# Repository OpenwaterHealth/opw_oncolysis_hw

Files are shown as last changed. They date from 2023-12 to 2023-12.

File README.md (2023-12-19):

# Preclinical Oncolysis Prototype
This repository contains the hardware designs as well as assembly and operation instructions for Openwater's preclinical oncolysis platform. The Openwater Preclinical Oncolysis Prototype is designed to help researchers investigate the effect of different ultrasound parameters on a variety of in vitro and preclinical in vivo targets. Certain acoustic parameters may be well suited for damaging cancer cells while sparing surrounding healthy tissue, and this system is designed to systematically explore such effects in a laboratory setting. 

For additional details on the preclinical oncolysis system and its applications, refer to the [wiki](https://wiki.openwater.health/index.php/Openwater_Wiki#Oncolysis).

## Getting Started
In addition to gathering the hardware listed here and following assmebly instructions, the software control code for the system needs to be installed from this repository: [opw_oncolysis_sw](https://github.com/OpenwaterHealth/opw_oncolysis_sw)

## Files contained in the Openwater Oncolysis Hardware Repository
* [v1.2 Oncolysis User Manual](Oncolysis%20User%20Manual%20(V1.2).pdf)
  * This user manual is for the in vitro and in vivo systems. It includes:
    * List of components needed for each assembly with links to off-the-shelf components
    * Instructions for how to assemble all of the components for both setups
    * References to part numbers of 3D-printed parts 
* [in vitro setup components](in%20vitro%20setup)
* [in vivo setup components](in%20vivo%20setup)
* [acoustic output validation setup](acoustic%20output%20validation%20setup)

## Contributing
We welcome contributions from the community. If you have ideas for improvements or find any issues, please open an issue or submit a pull request.

Before contributing, please read our [Contributing Guidelines](CONTRIBUTING.md).

## License
This project is licensed under the AGPLv3 License - see the [License](LICENSE) file for details.

## Disclaimer
CAUTION - Investigational device. Limited by Federal (or United States) law to investigational use. This system has not been evaluated by the FDA and is not designed for the treatment or diagnosis of any disease. It is provided AS-IS, with no warranties. User assumes all liability and responsibility for identifying and mitigating risks associated with use

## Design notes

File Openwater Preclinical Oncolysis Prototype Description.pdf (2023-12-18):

# Preclinical Oncolysis Prototype

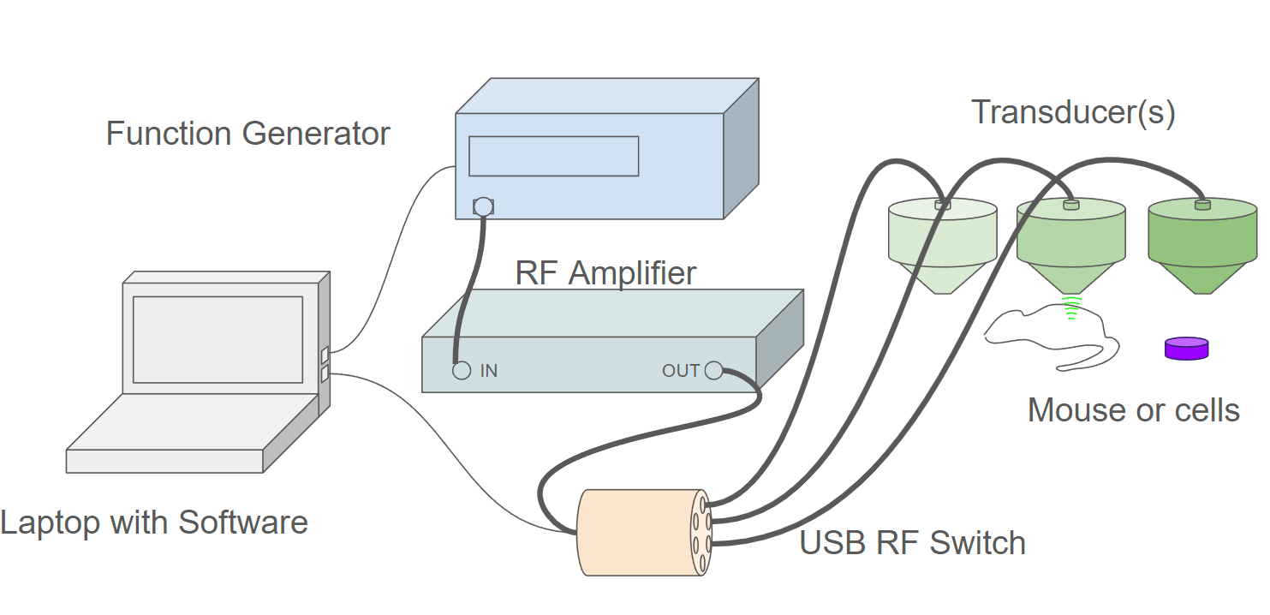
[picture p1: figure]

# Overview

The Openwater Preclinical Oncolysis Prototype is designed to help researchers investigate the effect of different ultrasound parameters on a variety of in vitro and preclinical in vivo targets. Certain acoustic parameters may be well suited for damaging cancer cells while sparing surrounding healthy tissue, and this system is designed to systematically explore such effects in a laboratory setting.

Multiple focused ultrasound transducers are connected to a programmable signal generator through an amplifier and a switch to select which transducer is active. Samples are placed beneath the transducer(s), using 3D-printed coupling cones filled with water to make a path for the ultrasound and set the depth of the focal spot within the target. This system is compatible with in vitro targets held in standard 6-well plates as well as with mouse flanks, through the
assistance of a stereotactic frame.

Controller software allows for configuration of
treatment parameters through a simple GUI application. With its default settings, the system can be configured to output focused ultrasound from the parameters shown in the table to the right. This allows for investigation of treatment parameters both within and well above the safety levels used for diagnostic ultrasound imaging.

# Getting Started

Additional information can be found in the following repositories:

- opw_oncolysis_hw (https://github.com/OpenwaterInternet/opw_oncolysis_hw) - assembly/operation instructions, mechanical drawings, 3D models
- opw_oncolysis_sw (https://github.com/OpenwaterInternet/opw_oncolysis_sw) - software to configure and operate the system
- opw_oncolysis_data (https://github.com/OpenwaterInternet/opw_oncolysis_data) - research data and experimental procedures

CAUTION - Investigational device. Limited by Federal (or United States) law to investigational use. This system has not been evaluated by the FDA and is not designed for the treatment or diagnosis of any disease. It is provided AS-IS, with no warranties. User assumes all liability and responsibility for identifying and mitigating risks associated with use

Parameter | Min | Max | Units
Frequency | 70 | 1000 | kHz
Output Voltage | 0 | 843 | V
Peak Negative Pressure | 0 | 1* | MPa
Mechanical Index | 0 | 3.8*
ISPPA | 0 | 100* | W/cm2
ISPTA | 0 | 1000* | mW/cm2
Burst Length | 2 | 40 | ms
Duty Cycle | 0.5 | 10 | %
Treatment Duration | 5 | 60 * 15 | seconds
*These are the maximum values that can be set when using the parameter as the target. If the parameter is derived and not used as the target, it may exceed this range to reach another parameter’s target value.

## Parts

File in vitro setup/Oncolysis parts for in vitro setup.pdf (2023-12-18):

# Oncolysis parts for v1.2 in vitro setup

- ONC- single treatment unit (assembly)
Off-the-shelf (OTS) parts (links)
- 1000-0173
- Acoustic absorbing foam (OTS) (https://www.acoustics.co.uk/product/apltile-sf5048/)
- 1000-0174
- Polysterene clear tank used in treatments (OTS) (https://www.usplastic.com/catalog/item.aspx?itemid=97006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)
- 1000-0175
- Internal O-ring for all the cones (OTS) (https://www.mcmaster.com/1288N237/)
- 1000-0176
- External O-ring for 25mm and 30mm cones (OTS) (https://www.mcmaster.com/5233T451/)
- 1000-0177
- External O-ring for 45mm and 60mm cones (OTS) (https://www.mcmaster.com/5233T442/)
- 1000-0178
- Thincert cell culture insert for 6 well plates (OTS) (https://shop.gbo.com/en/usa/products/bioscience/cell-culture-products/thincert-cell-culture-inserts/thincert-cell-culture-inserts-6well/657630.html) Tank covers zip
- 3000-0767
- Thincert holder/Laser cut in acrylic (3mm thickness)
- 3000-0768
- Hooks for Inner Tank Cover - 25mm, 3D printed
- 3000-0769
- Hooks for Inner Tank Cover - 30mm, 3D printed
- 3000-0770
- Hooks for Inner Tank Cover - 45mm, 3D printed
- 3000-0771
- Hooks for Inner Tank Cover - 60mm, 3D printed
Coupling cone zip
- 3000-0772
- 25mm cone used for 70,100 and 150kHz. 3D printed in 3rd party manufacturer (Xometry - Process: Stereolithography (SLA) Material: Accura ClearVue, Clear, Standard Resolution)
- 3000-0773
- 30mm cone used for 230 and 300kHz. 3D printed in 3rd party manufacturer (Xometry - Process: Stereolithography (SLA) Material: Accura ClearVue, Clear, Standard Resolution)
- 3000-0774
- 45mm cone used for 500 and 1000kHz. 3D printed in 3rd party manufacturer (Xometry - Process: Stereolithography (SLA) Material: Accura ClearVue, Clear, Standard Resolution)
- 3000-0775

- 60mm cone used for 670kHz. 3D printed in 3rd party manufacturer (Xometry -Process: Stereolithography (SLA) Material: Accura ClearVue, Clear, Standard Resolution)

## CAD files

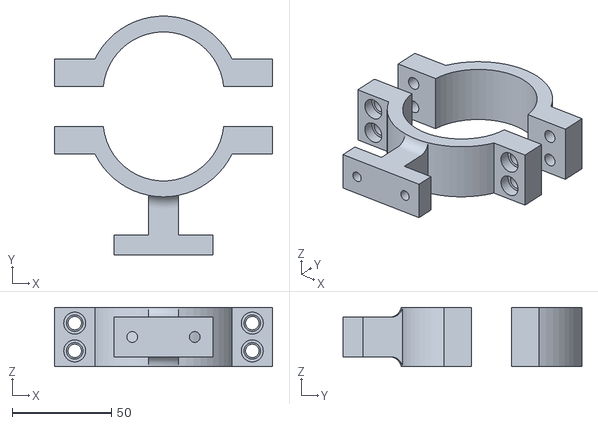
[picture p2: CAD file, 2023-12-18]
in vivo setup/3000-0819 - CONE FIXTURE, STEREOTACTIC FRAME, 61 MM.STL
110.0 x 120.4 x 30.0

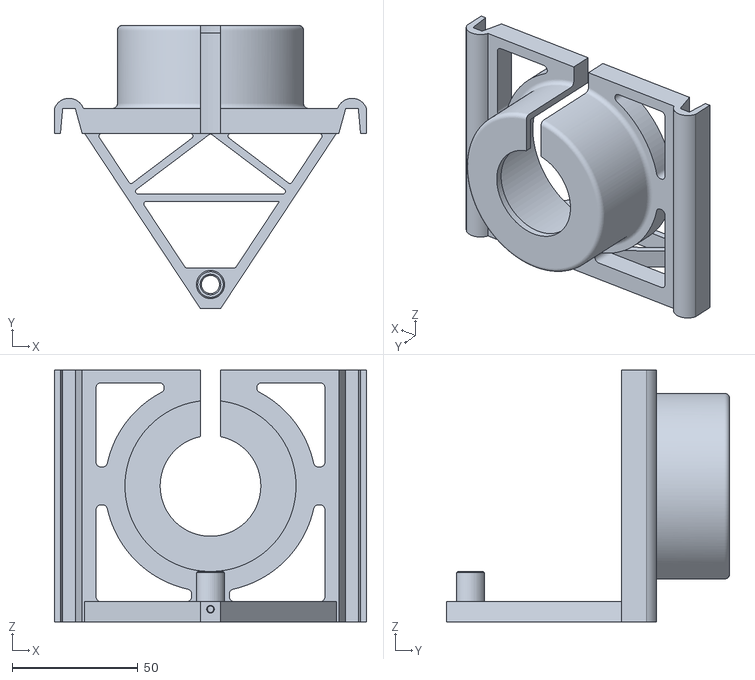
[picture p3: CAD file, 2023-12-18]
in vivo setup/3000-0816 - TRANSDUCER FRAME 2.STL
124.0 x 112.6 x 100.0

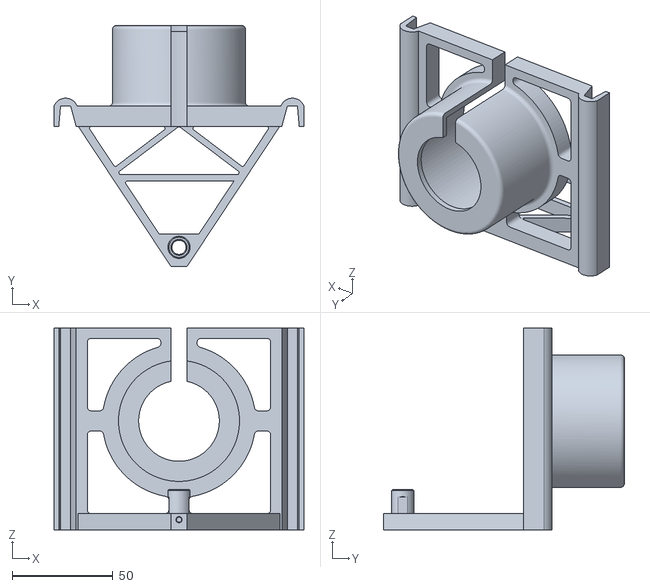
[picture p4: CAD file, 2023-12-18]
in vivo setup/3000-0815 - TRANSDUCER FRAME 1.STL
124.0 x 119.5 x 100.0

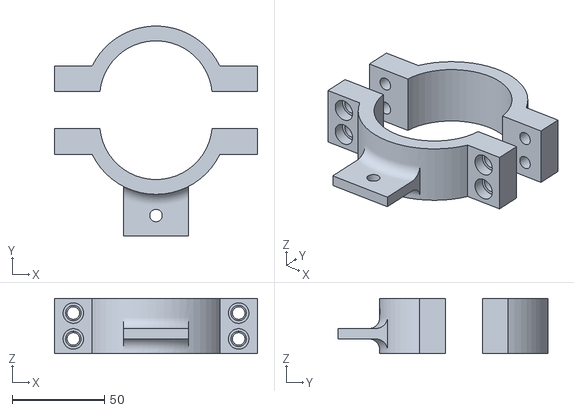
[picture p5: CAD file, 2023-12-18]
in vivo setup/3000-0817 - CONE FIXTURE, GOOSENECK, 61 MM.STL
110.0 x 113.6 x 30.0

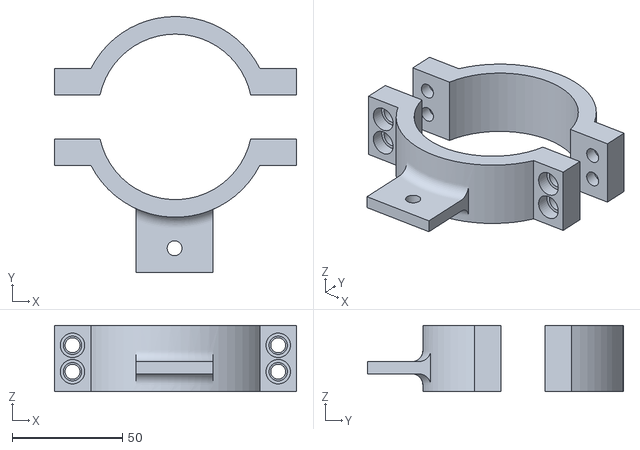
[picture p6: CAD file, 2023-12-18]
in vivo setup/3000-0818 - CONE FIXTURE, GOOSENECK, 70 MM.STL
110.0 x 116.3 x 30.0

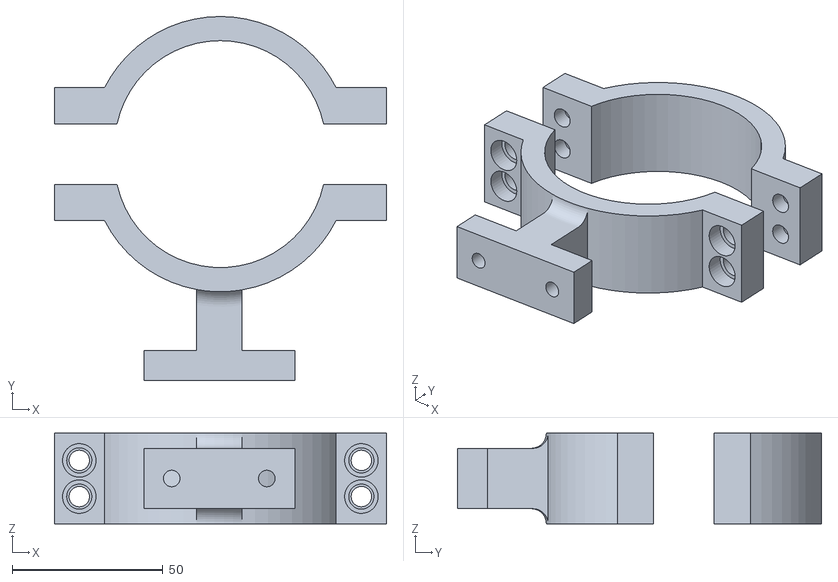
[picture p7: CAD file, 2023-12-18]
in vivo setup/3000-0820 - CONE FIXTURE, STEREOTACTIC FRAME, 70 MM.STL
110.0 x 120.6 x 30.0

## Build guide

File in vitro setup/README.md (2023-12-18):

# In Vitro Setup
This folder contains the following:
- `v0.1` Obsolete files and instructions for the 0.1 version of the _in vitro_ setup
- `ONC coupling cones.zip`: drawings needed to 3D print transducer coupling cones for in vitro setup
- `onc setup - single treatment unit (V1.2).easm`: Assembly drawings
- `ONC tank covers.zip`: drawings needed to 3D print in vitro setup tank covers
- `Oncolysis parts for in vitro setup.pdf`: BOM for _in vitro_ setup
- `OTS ONC parts.zip`: Lists of off-the-shelf (OTS) components with descriptions, part numbers, and links to purchase them
- `PORTABLE IN VITRO HYDROPHONE HOLDER ASSEMBLY.zip` contains mechanical drawings needed to 3D print the hydrophone holders and test the acoustic output of transducers on-site.
  * Calibration instructions are found in the User Manual.

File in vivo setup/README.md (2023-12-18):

# In Vivo Setup
- `3000-0815 - TRANSDUCER FRAME 1.STL`: Hydrophone Transducer Holders (150 kHz)
- `3000-0816 - TRANSDUCER FRAME 2.STL`: Hydrophone Transducer Holders (100, 200 kHz +)
- `3000-0817 - CONE FIXTURE, GOOSENECK,  61 MM.STL`: Gooseneck Cone Holder, (150 kHz)
- `3000-0818 - CONE FIXTURE, GOOSENECK, 70 MM.STL`: Gooseneck Cone Holder, (100, 200 kHz)
- `3000-0819 - CONE FIXTURE, STEREOTACTIC FRAME, 61 MM.STL`: Stereotactic Frame Holder, (150 kHz)
- `3000-0820 - CONE FIXTURE, STEREOTACTIC FRAME, 70 MM.STL`: Stereotactic Frame Holder, (100, 200 kHz)

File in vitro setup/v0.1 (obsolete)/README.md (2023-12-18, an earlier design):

# v0.1 In Vitro Setup (Obsolete)
This folder contains:
- `05-03 onc Setup (V0.1).easm`
- `HYDROPHONE HOLDERS L AND R.zip`
- `Oncolysis in vitro only User Manual (V0.1).pdf`: Manual describing the original system used to perform the in vitro cell culture treatment of GBM constructs. 
  * This is an obsolete manual as the system was upgraded due to issues with contamination and to improve its ease of use
